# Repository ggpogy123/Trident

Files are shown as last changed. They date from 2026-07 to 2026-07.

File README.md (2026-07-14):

# Trident

A custom, hardware control board featuring a esp32, dual-axis joystick, and three independent SPI displays. 

## Overview
Trident is designed to be a modular, compact interface board. By routing the SPI MOSI, SCK, and LED lines in a daisy chain configuration, the board allows a single ESP32 microcontroller to drive three 2.8 inch TFT LCD screens simultaneously while reading analog inputs from a PS2 style joystick. 

## Visuals






## Hardware Specifications
* **Microcontroller:** ESP32 38-pin Development Board
* **Displays:** 3x 2.8 inch TFT LCDs (ILI9341)
* **Input:** Dual Axis PS2 Analog Joystick Module (KY-023)
* **PCB Specs:** 2-layer FR4, 195.5 x 61.5 mm, 1.6mm thickness

## Key Design Features
* **Wi-Fi Optimization:**  The boundary of the PCB has been cut to ensure that the antenna of the ESP is placed outside the fiberglass. This is done to prevent any kind of interference.
* **Current Handling:** VCC lines are routed with 0.7mm trace widths.
* **Ground Plane:** A copper pour layer has been used to connect all GND points.

## Pin layout

### All Displays

| Pin Name | Connection Type | ESP32 pin | Working |
| :--- | :--- | :--- | :--- |
| **VCC** | Power | 5V | Power |
| **GND** | Ground | GND | Ground|
| **SPI_MOSI**| SPI Data | GPIO 23 | Master Out Slave In |
| **SPI_SCK** | SPI Clock | GPIO 18 | Serial Clock |
| **D_RST** | Shared Reset | GPIO 5 | Hardware reset |
| **LED_BL** | Backlight | GPIO 19 | Backlight |

### Display-Specific Pins

| Screen Number | Chip Select pin | Data/Command pin|
| :--- | :--- | :--- |
| **Display 1 (J1)** | GPIO 21 | GPIO 22 |
| **Display 2 (J2)** | GPIO 27 | GPIO 13 |
| **Display 3 (J3)** | GPIO 15 | GPIO 14 |

### Joystick (J4)

| Joystick Pin | Connection Type | ESP32 pin | Working |
| :--- | :--- | :--- | :--- |
| **VCC** | Power | 5V | Power |
| **GND** | Ground | GND | Ground |
| **JOY_X** | Analog Input | GPIO 36 | X-Axis|
| **JOY_Y** | Analog Input |GPIO 39 | Y-Axis  |
| **JOY_SW** | Digital Input | GPIO 32 | Click |

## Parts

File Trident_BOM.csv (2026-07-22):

Trident Bill of Materials
Item # | Manufacturer | Item name | Quantity | Price of each item | Shipping Cost | Total Price (inr) | Buying from | Links
1 |  | 2.8 inch SPI Screen Module TFT Interface 240 x 320 without Touch | 3 | 516 | 0 | 1548 | Robu.in | https://robu.in/product/2-8-inch-spi-screen-module-tft-interface-240-x-320-without-touch/
2 |  | ESP32 (38 Pin) WiFi + Bluetooth NodeMCU-32 Development Board | 1 | 425 | 49 | 474 | Robobraze.com | https://robocraze.com/products/esp32-development-board
3 | Embeddinator | Dual Axis PS2 Joystick Module | 1 | 99 | 143 | 371 | Amazon | https://www.amazon.in/Embeddinator-Dual-Axis-Joystick-Module/dp/B09XXKDNQ7
4 | KITS4CREATORS | 2.54mm 0.1" 1x40Pin Female Socket Pin Row 40P Single Row Straight Female/Male Socket/Pin Header Connectors, Pack of 10 | 1 | 129 | Combined with above | Combined with above | Amazon | https://www.amazon.in/KITS4CREATORS-2-54mm-1x40Pin-Straight-Connectors/dp/B0CW5WNNWJ?nsdOptOutParam=true
5 | lioncircuits | PCB | 1 | 2161 | 0 | 2161 | lioncircuits.com | -
 |  | Total | 7 | 3330 | 192 | 4554

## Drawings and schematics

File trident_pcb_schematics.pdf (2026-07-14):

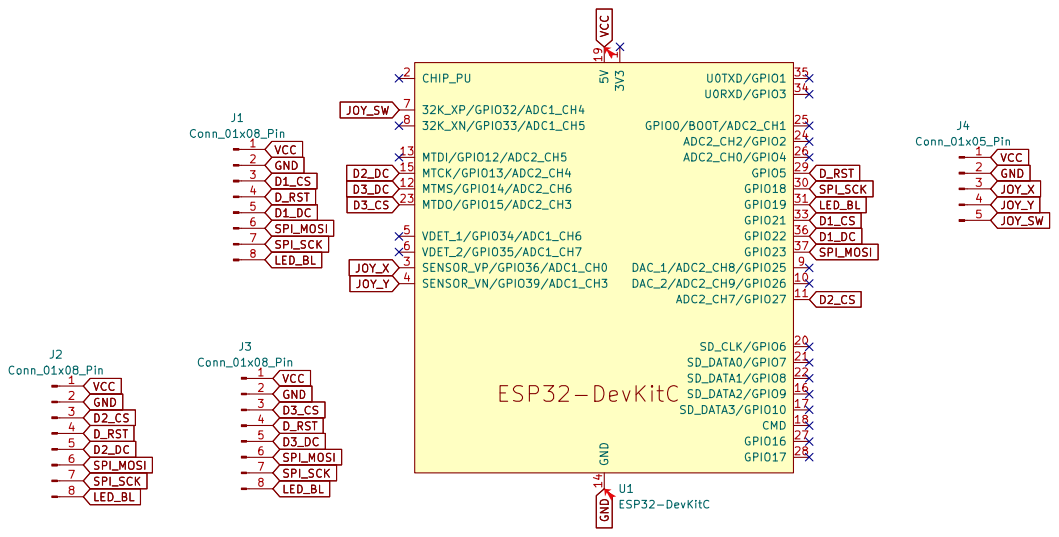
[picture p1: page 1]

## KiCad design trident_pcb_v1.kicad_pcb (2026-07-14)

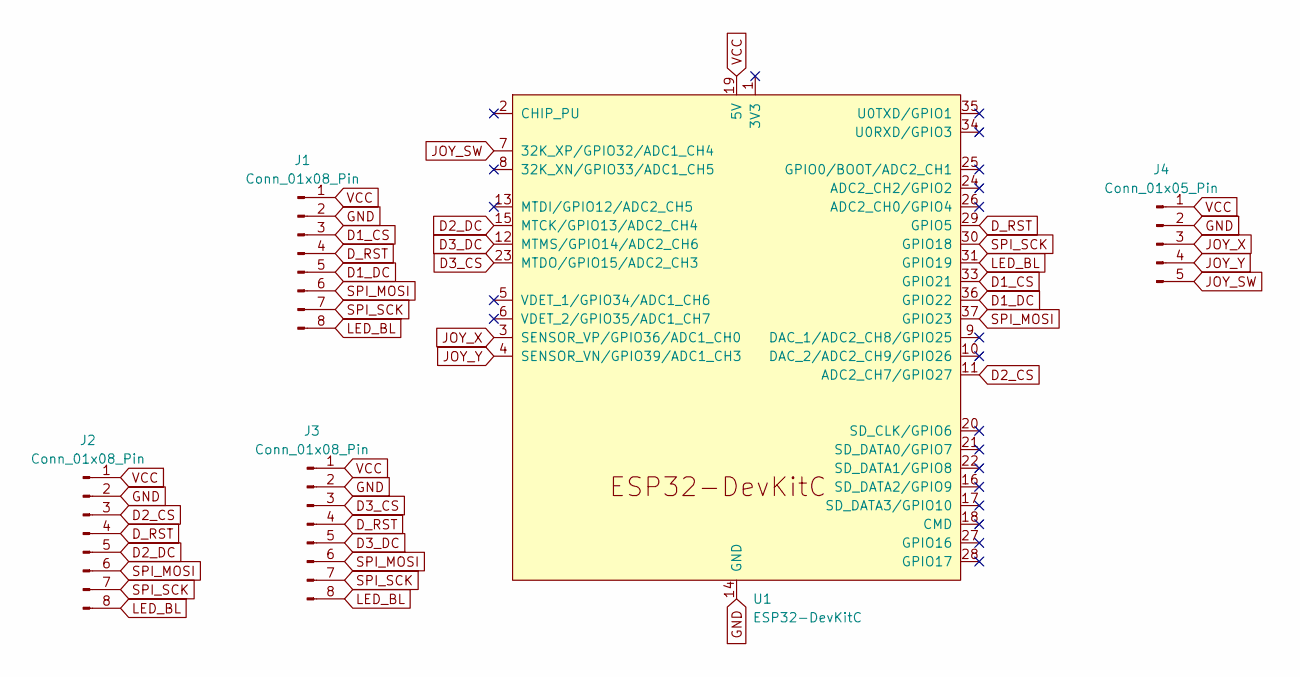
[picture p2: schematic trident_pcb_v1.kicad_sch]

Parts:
J1, J2, J3: Conn_01x08_Pin; PinHeader_1x08_P2.54mm_Vertical
J4: Conn_01x05_Pin; PinHeader_1x05_P2.54mm_Vertical
U1: ESP32-DevKitC

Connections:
D1_CS: J1.3, U1.33 (GPIO21)
D1_DC: J1.5, U1.36 (GPIO22)
D2_CS: J2.3, U1.11 (ADC2_CH7/GPIO27)
D2_DC: J2.5, U1.15 (MTCK/GPIO13/ADC2_CH4)
D3_CS: J3.3, U1.23 (MTDO/GPIO15/ADC2_CH3)
D3_DC: J3.5, U1.12 (MTMS/GPIO14/ADC2_CH6)
D_RST: J1.4, J2.4, J3.4, U1.29 (GPIO5)
GND: J1.2, J2.2, J3.2, J4.2, U1.14 (GND), U1.32 (GND), U1.38 (GND)
JOY_SW: J4.5, U1.7 (32K_XP/GPIO32/ADC1_CH4)
JOY_X: J4.3, U1.3 (SENSOR_VP/GPIO36/ADC1_CH0)
JOY_Y: J4.4, U1.4 (SENSOR_VN/GPIO39/ADC1_CH3)
LED_BL: J1.8, J2.8, J3.8, U1.31 (GPIO19)
SPI_MOSI: J1.6, J2.6, J3.6, U1.37 (GPIO23)
SPI_SCK: J1.7, J2.7, J3.7, U1.30 (GPIO18)
VCC: J1.1, J2.1, J3.1, J4.1, U1.19 (5V)

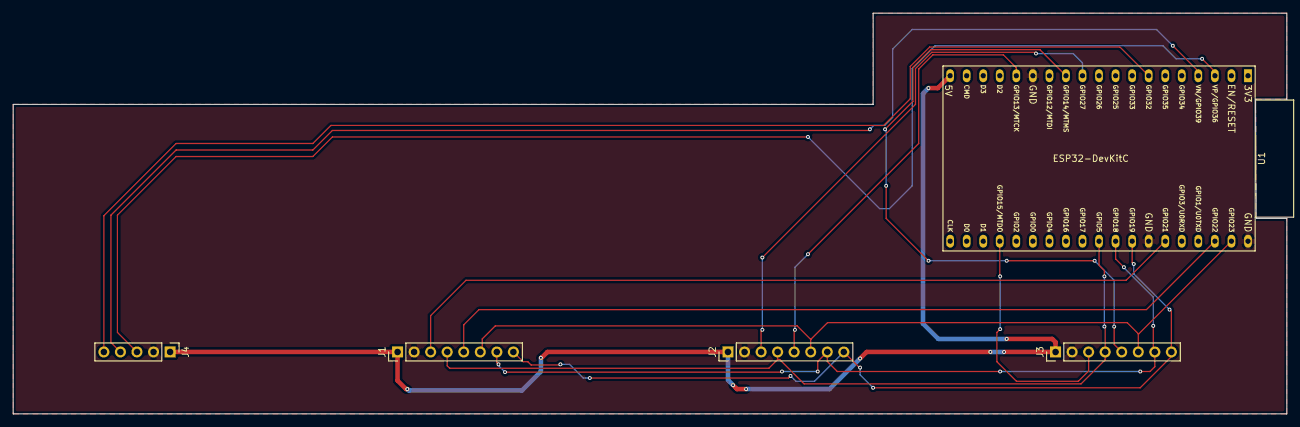
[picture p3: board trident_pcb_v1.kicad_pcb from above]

Board: 2 copper layers, 195.5 x 61.5 mm, 5 parts (0 on the bottom side), 15 nets.

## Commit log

2026-06-16 Add schematic file
2026-07-03 Add csv BOM
    [Trident_BOM.csv]
2026-07-03 trident schematics
    [trident_pcb_v1.kicad_sch]
2026-07-14 Add pin layout and joystick connection details to README
2026-07-14 Update GPIO pin for Display 2 in README
